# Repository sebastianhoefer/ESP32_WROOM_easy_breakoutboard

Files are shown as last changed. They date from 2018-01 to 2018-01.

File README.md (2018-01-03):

# ESP32_WROOM_easy_breakoutboard
ESP32 WROOM/ breadboard prototyping/Eagle

This is an easy-to-use ESP32 WROOM breakout board with built-in voltage regulator
and two switches for the reset and boot modes. It works well for getting started with
the ESP32 system. Feel free to optimize the board with a 3.3V UART bridge.

Have a lot of fun!

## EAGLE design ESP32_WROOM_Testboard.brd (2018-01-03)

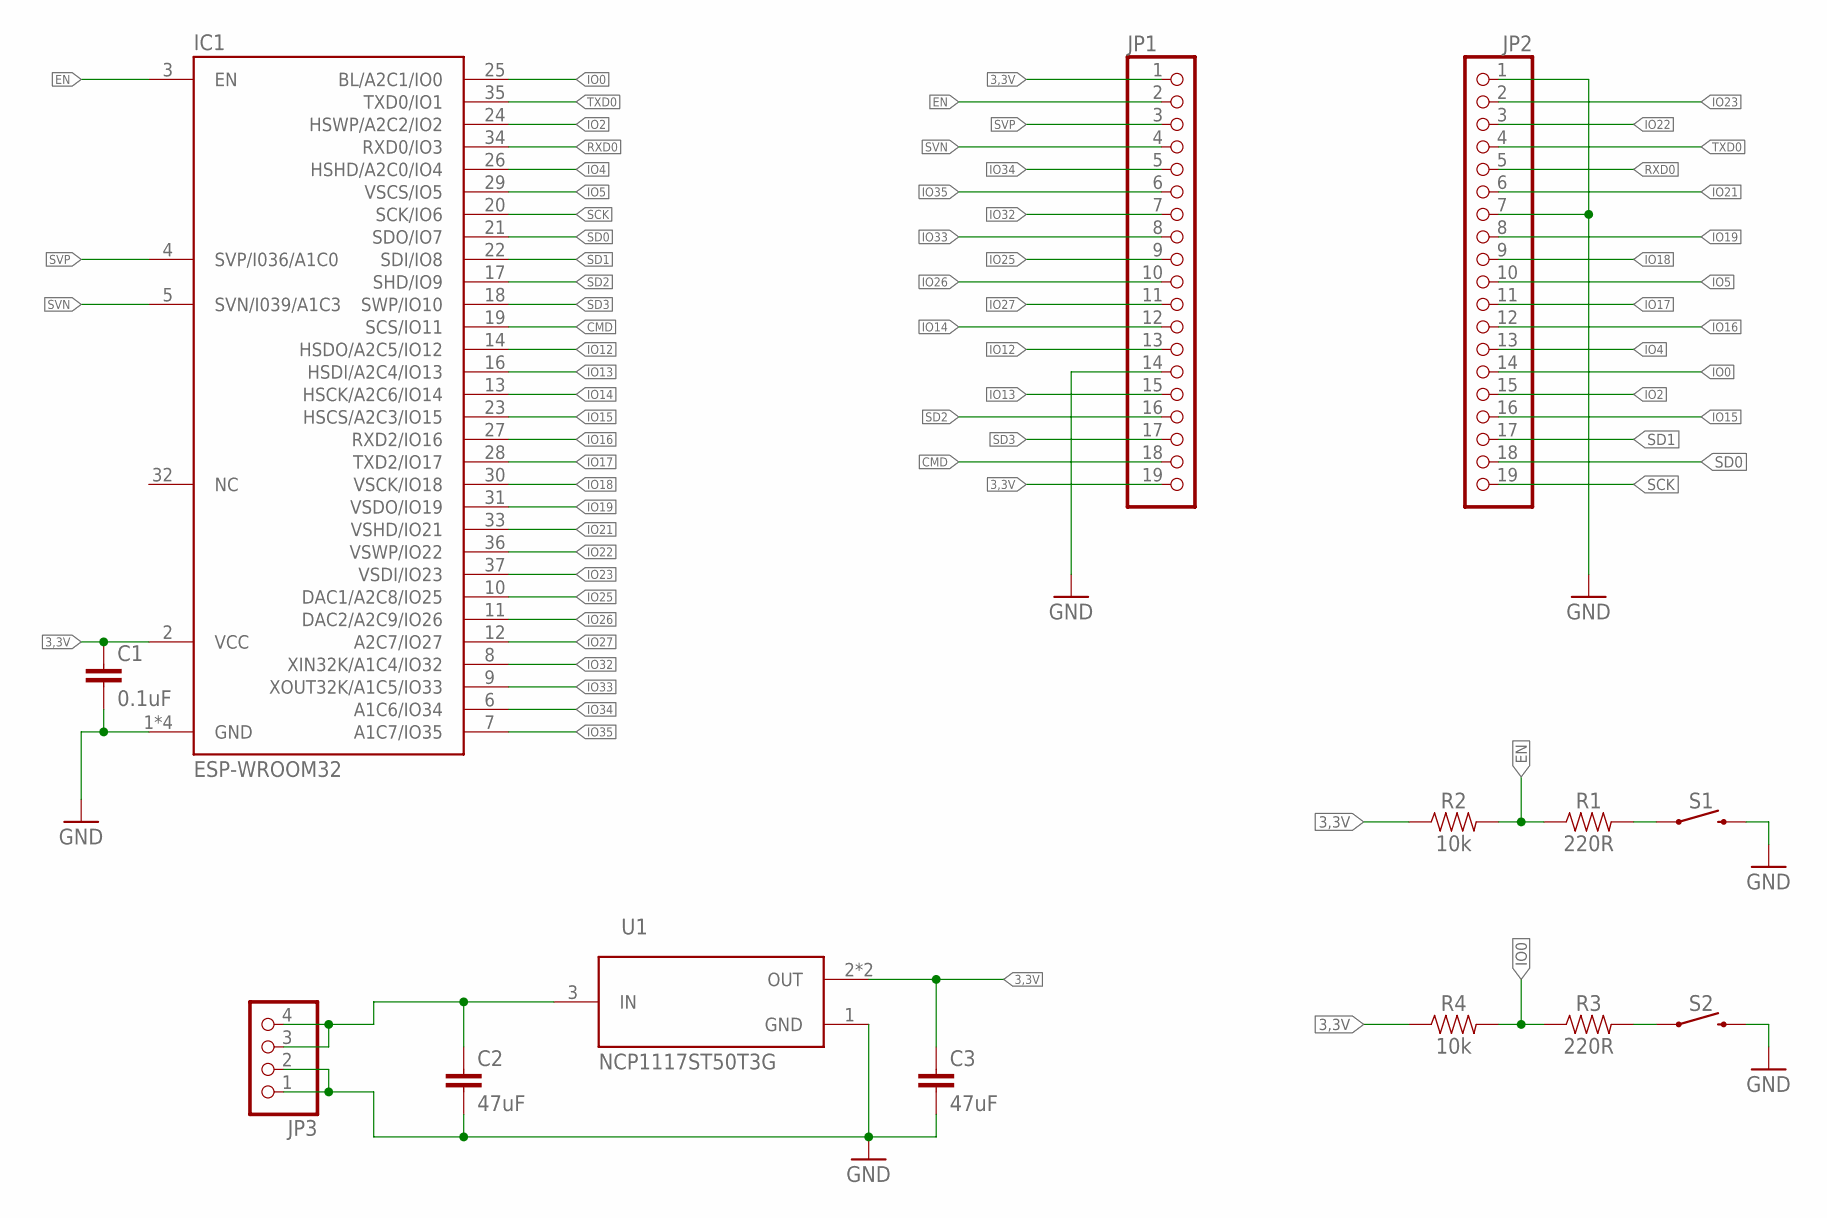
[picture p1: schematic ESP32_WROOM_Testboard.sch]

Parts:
C1: 0.1uF; 0603
C2, C3: 47uF; 0603
IC1: ESP-WROOM32
JP1, JP2: PINHD-1X19; 1X19
JP3: PINHD-1X4; 1X04
R1, R3: 220R; 0805
R2, R4: 10k; 0805
S1, S2: MOMENTARY-SWITCH-SPST-SMD-5.2-REDUNDANT; TACTILE_SWITCH_SMD_5.2MM
U1: NCP1117ST50T3G; SOT230P700X180-4N

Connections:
3,3V: C1.1, C3.1, IC1.2 (VCC), JP1.1, JP1.19, R2.1, R4.1, U1.2 (OUT), U1.4 (OUT)
CMD: IC1.19 (SCS/IO11), JP1.18
EN: IC1.3 (EN), JP1.2, R1.1, R2.2
GND: C1.2, C2.2, C3.2, IC1.1 (GND), IC1.15 (GND), IC1.38 (GND), IC1.TP (GND), JP1.14, JP2.1, JP2.7, JP3.1, JP3.2, S1.3 (2), S1.4 (2), S2.3 (2), S2.4 (2), U1.1 (GND)
IO0: IC1.25 (BL/A2C1/IO0), JP2.14, R3.1, R4.2
IO2: IC1.24 (HSWP/A2C2/IO2), JP2.15
IO4: IC1.26 (HSHD/A2C0/IO4), JP2.13
IO5: IC1.29 (VSCS/IO5), JP2.10
IO12: IC1.14 (HSDO/A2C5/IO12), JP1.13
IO13: IC1.16 (HSDI/A2C4/IO13), JP1.15
IO14: IC1.13 (HSCK/A2C6/IO14), JP1.12
IO15: IC1.23 (HSCS/A2C3/IO15), JP2.16
IO16: IC1.27 (RXD2/IO16), JP2.12
IO17: IC1.28 (TXD2/IO17), JP2.11
IO18: IC1.30 (VSCK/IO18), JP2.9
IO19: IC1.31 (VSDO/IO19), JP2.8
IO21: IC1.33 (VSHD/IO21), JP2.6
IO22: IC1.36 (VSWP/IO22), JP2.3
IO23: IC1.37 (VSDI/IO23), JP2.2
IO25: IC1.10 (DAC1/A2C8/IO25), JP1.9
IO26: IC1.11 (DAC2/A2C9/IO26), JP1.10
IO27: IC1.12 (A2C7/IO27), JP1.11
IO32: IC1.8 (XIN32K/A1C4/IO32), JP1.7
IO33: IC1.9 (XOUT32K/A1C5/IO33), JP1.8
IO34: IC1.6 (A1C6/IO34), JP1.5
IO35: IC1.7 (A1C7/IO35), JP1.6
unnamed: C2.1, JP3.3, JP3.4, U1.3 (IN)
unnamed: R1.2, S1.1, S1.2 (1)
unnamed: R3.2, S2.1, S2.2 (1)
RXD0: IC1.34 (RXD0/IO3), JP2.5
SCK: IC1.20 (SCK/IO6), JP2.19
SD0: IC1.21 (SDO/IO7), JP2.18
SD1: IC1.22 (SDI/IO8), JP2.17
SD2: IC1.17 (SHD/IO9), JP1.16
SD3: IC1.18 (SWP/IO10), JP1.17
SVN: IC1.5 (SVN/I039/A1C3), JP1.4
SVP: IC1.4 (SVP/I036/A1C0), JP1.3
TXD0: IC1.35 (TXD0/IO1), JP2.4

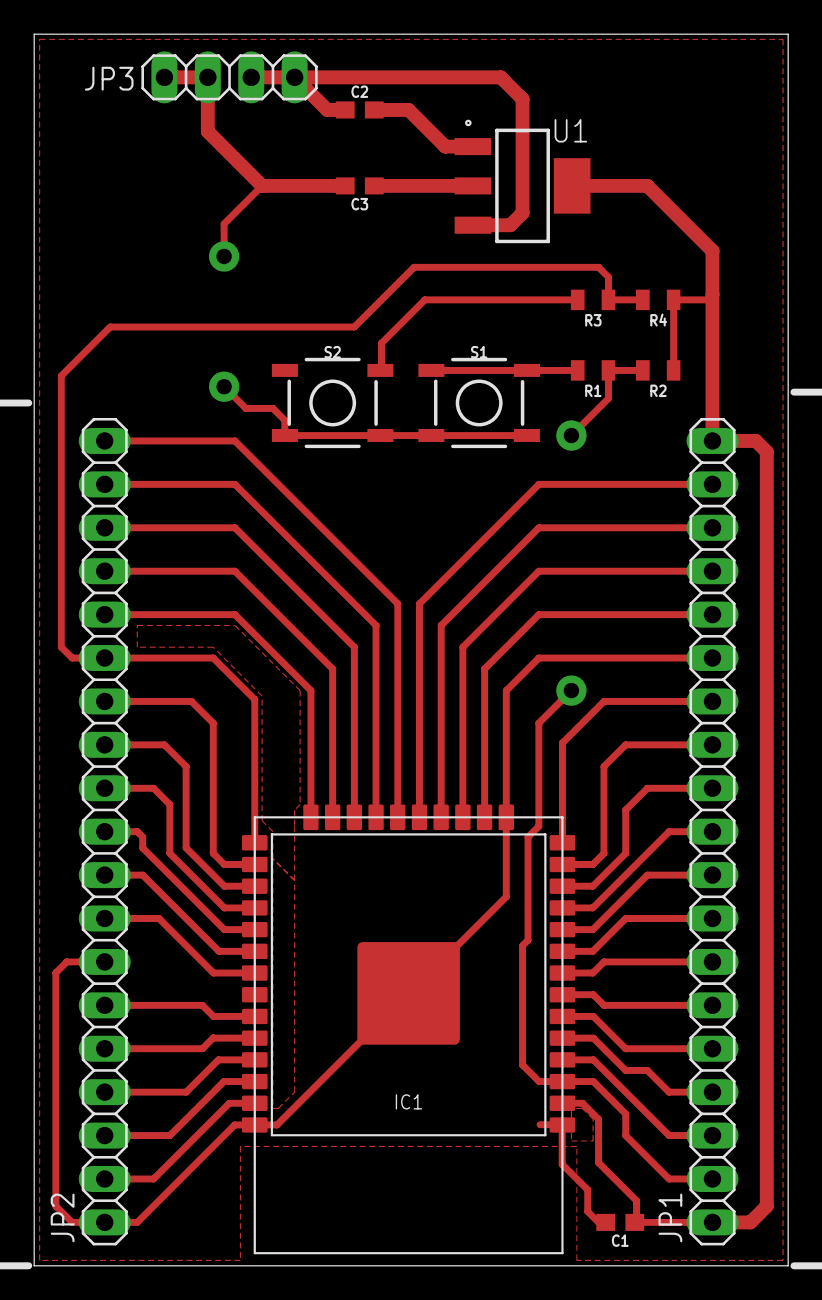
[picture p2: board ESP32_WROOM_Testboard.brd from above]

Board: 2 copper layers, 44.1 x 72.1 mm, 14 parts (0 on the bottom side), 38 nets.

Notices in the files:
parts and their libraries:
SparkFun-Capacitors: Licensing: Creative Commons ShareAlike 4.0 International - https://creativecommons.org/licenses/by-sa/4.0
